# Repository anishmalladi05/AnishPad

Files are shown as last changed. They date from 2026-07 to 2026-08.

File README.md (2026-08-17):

# AnishPad
I made this Macropad because I wanted one that was more customizable then my last, which only had 4 buttons. That time, the rotary encoder got the better of me, so I wanted to successfully put one in this time, which I did!
<br></br>
A 5 key, 1 rotary encoder, and 128 x 32 oled display macropad.

# Images:

Screenshot 2026-08-17 at 3 21 54 PM
Screenshot 2026-08-17 at 3 21 58 PM
Screenshot 2026-08-17 at 3 22 01 PM
Screenshot 2026-08-17 at 3 22 04 PM

<br></br>
# To Flash:
Put the microcontroller in bootloader mode. (Hold reset, double press boot, release reset)
<br></br>
Plug into computer
<br></br>
Drag UF2 file into microcontroller
<br></br>

Replace boot_out.txt with boot_out.txt in my gihub repo under CIRCUITPY FILES
<br></br>
Replace code.py with code.py from my repo
<br></br>
Add boot.txt from my repo
<br></br>
Add boot.py from my repo
<br></br>

It should start working!

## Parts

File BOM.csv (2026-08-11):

Item | "Link" | "Price"
5x MX CHERRY SWITCES: | https://www.amazon.com/CHERRY-Switch-Mechanical-Keyboard-Switches/dp/B0FYR9X5QH?sp_csd=d2lkZ2V0TmFtZT1zcF9hdGY | "$15"
1x 128x32 OLED panel (needs to allow for 5v): | https://www.amazon.com/dp/B079BN2J8V?lv=shuf&channelId=500&plpRedirect=mhFallback&th=1 | "$8"
5x Keycaps (Can buy own, or 3d print files are in the CAD folder): | https://www.amazon.com/Elacgap-Profile-switches-Mechanical-Keyboard/dp/B0CQ2Y15Y5 | "$12"
1x SEEEDUINO XIAO RP2040: | https://www.seeedstudio.com/Seeed-Studio-XIAO-ESP32S3-Pre-Soldered-p-6334.html | "$4"
1x Ability to solder: | Please provide yourself | "Free!"
1x EC11 Push button rotary encoder (the one wihtout the PCB attached): | https://www.amazon.com/QSYZAIL-Rotary-Encoder-Compatible-Arduino/dp/B0G528SYTB?sp_csd=d2lkZ2V0TmFtZT1zcF9hdGY | "$8"
1x PCB (found in PCB files): | jlcpcb.com | "$4"
1x UCB-C cable to connect to device: | https://www.amazon.com/Amazon-Basics-Charger-480Mbps-Certified/dp/B01GGKZ2SC?sp_csd=d2lkZ2V0TmFtZT1zcF9hdGY | "$10"
1x Coding skills (only if you want to customize or make it work for windows): | Please provide yourself | "Free again!"
1x 3D printer with 1 spool filament: | https://us.store.bambulab.com/products/a1-mini?from=navigation | "$220"
3x Socket head cap screws SHCS.M316-50: | https://www.mcmaster.com/products/cap-screws/fastener-head-type~socket/?matchtype=p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 | "$5"

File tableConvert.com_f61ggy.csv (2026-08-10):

5x MX CHERRY SWITCES: | https://www.amazon.com/CHERRY-Switch-Mechanical-Keyboard-Switches/dp/B0FYR9X5QH?sp_csd=d2lkZ2V0TmFtZT1zcF9hdGY
1x 128x32 OLED panel (needs to allow for 5v): | https://www.amazon.com/dp/B079BN2J8V?lv=shuf&channelId=500&plpRedirect=mhFallback&th=1
5x Keycaps (Can buy own, or 3d print files are in the CAD folder): | https://www.amazon.com/Elacgap-Profile-switches-Mechanical-Keyboard/dp/B0CQ2Y15Y5
1x SEEEDUINO XIAO RP2040: | https://www.seeedstudio.com/Seeed-Studio-XIAO-ESP32S3-Pre-Soldered-p-6334.html
1x Ability to solder: | Please provide yourself
1x EC11 Push button rotary encoder (the one wihtout the PCB attached): | https://www.amazon.com/QSYZAIL-Rotary-Encoder-Compatible-Arduino/dp/B0G528SYTB?sp_csd=d2lkZ2V0TmFtZT1zcF9hdGY
1x PCB (found in PCB files): | jlcpcb.com
1x UCB-C cable to connect to device: | https://www.amazon.com/Amazon-Basics-Charger-480Mbps-Certified/dp/B01GGKZ2SC?sp_csd=d2lkZ2V0TmFtZT1zcF9hdGY
1x Coding skills (only if you want to customize or make it work for windows): | Please provide yourself
1x 3D printer with 1 spool filament: | https://us.store.bambulab.com/products/a1-mini?from=navigation
3x Socket head cap screws SHCS.M316-50: | https://www.mcmaster.com/products/cap-screws/fastener-head-type~socket/?matchtype=p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

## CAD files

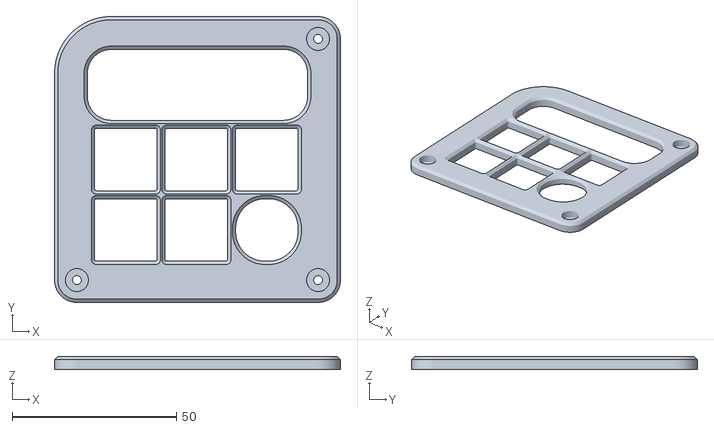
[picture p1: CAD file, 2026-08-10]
AnishPad CAD/TopCover.stl
87.0 x 87.0 x 4.04

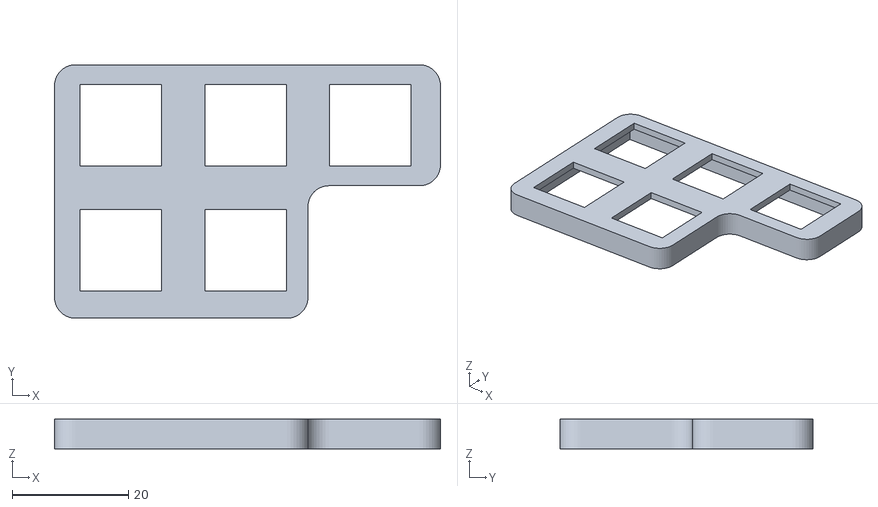
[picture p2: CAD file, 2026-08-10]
AnishPad CAD/KeyAligners.stl
66.3 x 43.5 x 5.13

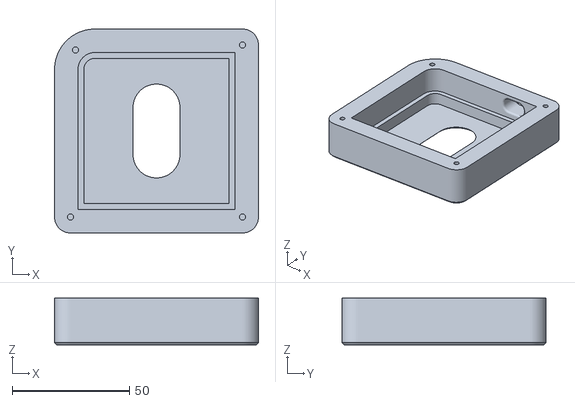
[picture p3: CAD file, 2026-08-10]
AnishPad CAD/BottomCover.stl
87.0 x 87.0 x 20.0

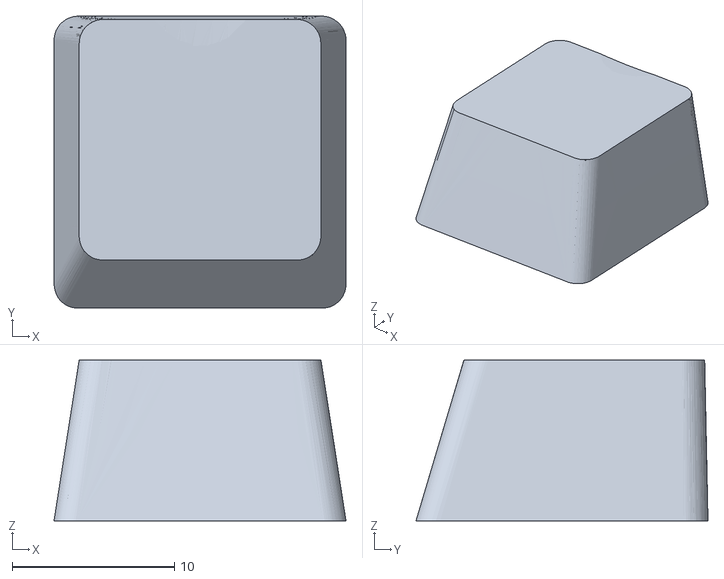
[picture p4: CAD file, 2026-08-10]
AnishPad CAD/KeyCap.stl
18.0 x 18.0 x 9.91

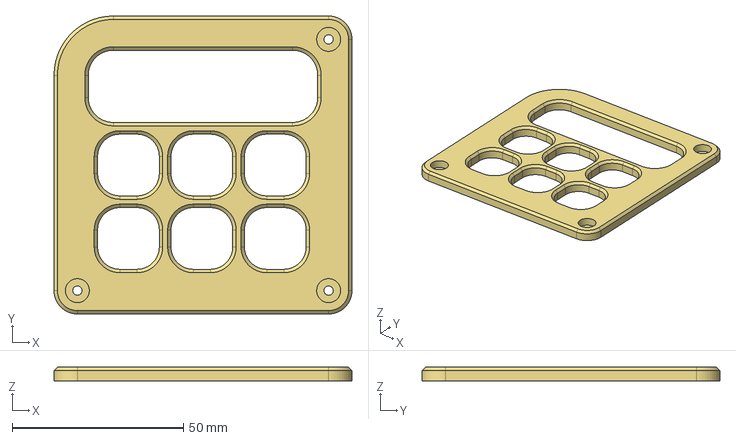
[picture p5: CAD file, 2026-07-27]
AnishPad CAD/AnishPad Case Top.step
87.0 x 87.0 x 4.04 mm

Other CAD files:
AnishPad CAD/AnishPad Keycap.step
AnishPad CAD/AnishPad Case Bottom.step

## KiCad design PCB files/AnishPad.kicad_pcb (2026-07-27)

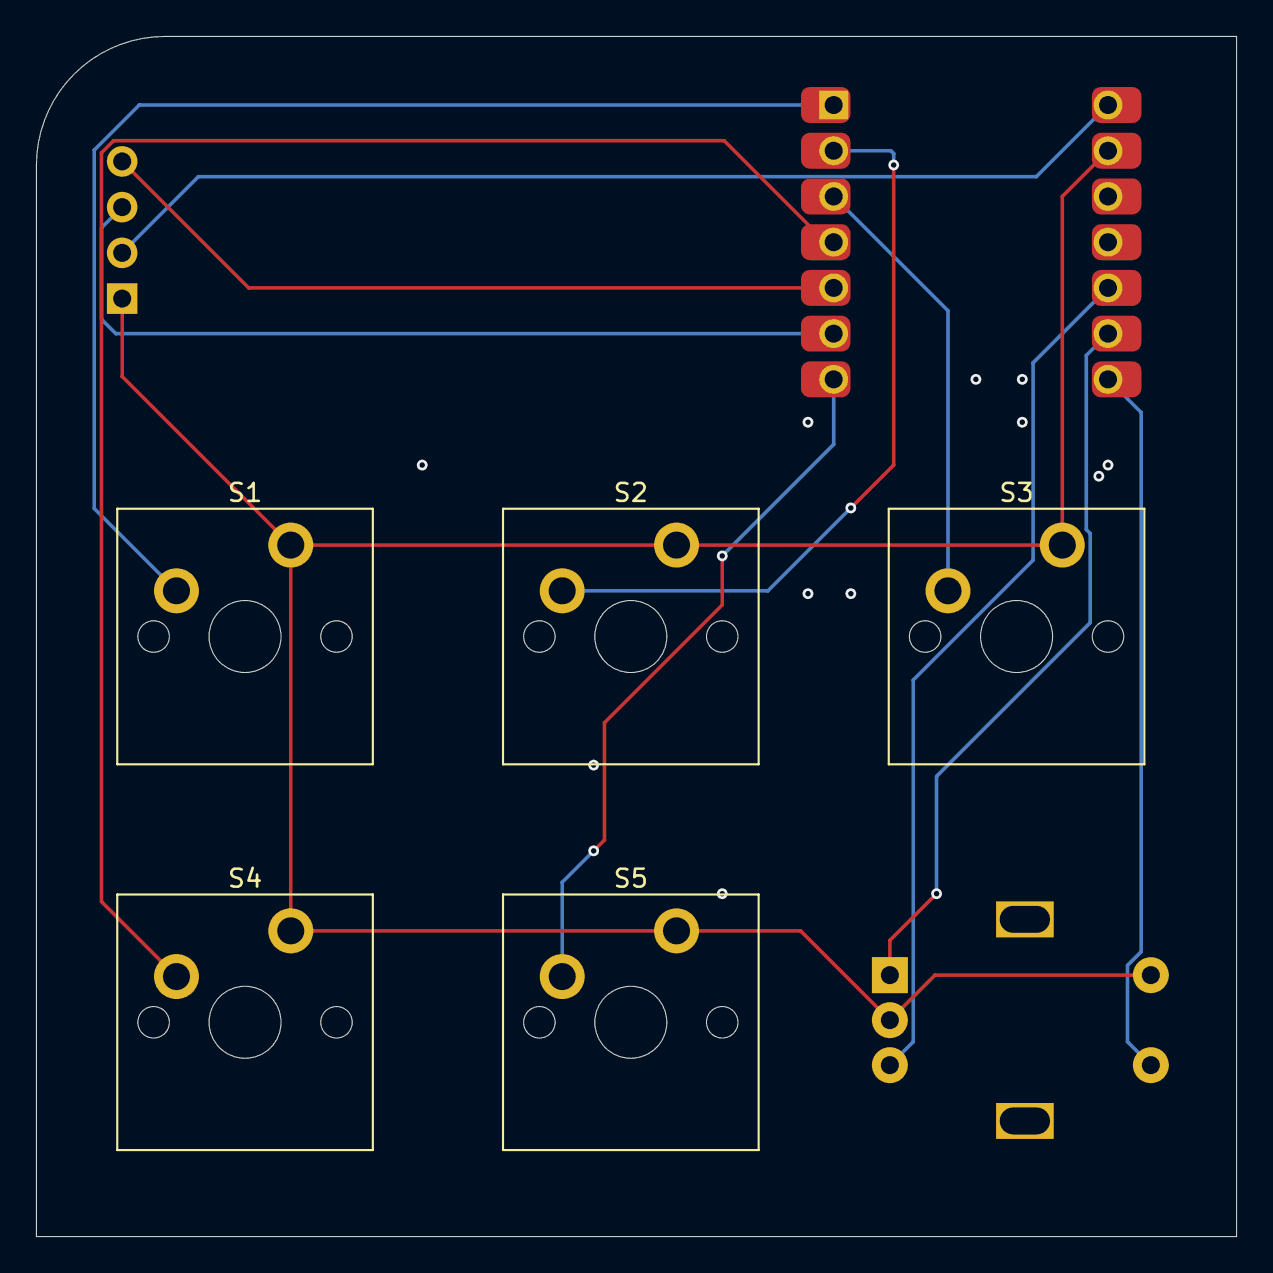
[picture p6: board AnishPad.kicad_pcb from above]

Board: 2 copper layers, 66.7 x 66.7 mm, 8 parts (0 on the bottom side), 12 nets.

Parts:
J1: OLED_128x32
S1, S2, S3, S4, S5: MX_PCB_1.00u
SW6: RotaryEncoder_Switch; Encoder_EC11_MX
U1: MOUDLE-SEEEDUINO-XIAO; Seeed_XIAO_RP2040

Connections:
1: S1.1, U1.1 (PA02_A0_D0)
2: S2.1, U1.2 (PA4_A1_D1)
3: S3.1, U1.3 (PA10_A2_D2)
4: S4.1, U1.4 (PA11_A3_D3)
5: J1.4 (SDA), U1.5 (PA8_A4_D4_SDA)
6: J1.3 (SCL), U1.6 (PA9_A5_D5_SCL)
7: S5.1, U1.7 (PB08_A6_D6_TX)
8: SW6.S1, U1.8 (PB09_A7_D7_RX)
9: SW6.A, U1.9 (PA7_A8_D8_SCK)
10: SW6.B, U1.10 (PA5_A9_D9_MISO)
13: J1.1 (GND), S1.2, S2.2, S3.2, S4.2, S5.2, SW6.C, SW6.S2, U1.13 (GND)
14: J1.2 (VCC), U1.14 (5V)

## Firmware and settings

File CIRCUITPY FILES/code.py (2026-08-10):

import math
import time
import board
import displayio
import terminalio
import digitalio
import usb_hid
from adafruit_display_text import label
import adafruit_displayio_ssd1306
from adafruit_hid.keyboard import Keyboard
from adafruit_hid.keycode import Keycode
from adafruit_hid.consumer_control import ConsumerControl
from adafruit_hid.consumer_control_code import ConsumerControlCode

try:
    from i2cdisplaybus import I2CDisplayBus
except ImportError:
    from displayio import I2CDisplay as I2CDisplayBus

displayio.release_displays()

i2c = board.I2C()
display_bus = I2CDisplayBus(i2c, device_address=0x3C)

WIDTH = 128
HEIGHT = 32

display = adafruit_displayio_ssd1306.SSD1306(display_bus, width=WIDTH, height=HEIGHT, rotation=0)

splash = displayio.Group()
display.root_group = splash

# --- UI LABELS SETUP ---
layer_label = label.Label(terminalio.FONT, text="N", color=0xFFFFFF)
layer_label.x = 100
layer_label.y = 8
splash.append(layer_label)

mode_label = label.Label(terminalio.FONT, text="VOL", color=0xFFFFFF)
mode_label.x = 100
mode_label.y = 24
splash.append(mode_label)

grid_labels = []
coords = [(10, 8), (52, 8), (10, 24), (52, 24)]
for coord in coords:
    lbl = label.Label(terminalio.FONT, text="-", color=0xFFFFFF)
    lbl.x = coord[0]
    lbl.y = coord[1]
    splash.append(lbl)
    grid_labels.append(lbl)

# --- HID & INPUT SETUP ---
kbd = Keyboard(usb_hid.devices)
cc = ConsumerControl(usb_hid.devices)

# Switches S1-S5 mapped to D0, D1, D2, D3, TX
switch_pins = [board.D0, board.D1, board.D2, board.D3, board.TX]
switches = []
for pin in switch_pins:
    sw = digitalio.DigitalInOut(pin)
    sw.direction = digitalio.Direction.INPUT
    sw.pull = digitalio.Pull.UP
    switches.append(sw)

last_switch_states = [True] * len(switches)

# Rotary Encoder Push Button (SW6) on RX
encoder_button = digitalio.DigitalInOut(board.RX)
encoder_button.direction = digitalio.Direction.INPUT
encoder_button.pull = digitalio.Pull.UP
last_button_state = True

# Software Rotary Encoder Pins on D8 and D9
enc_a = digitalio.DigitalInOut(board.D8)
enc_a.direction = digitalio.Direction.INPUT
enc_a.pull = digitalio.Pull.UP

enc_b = digitalio.DigitalInOut(board.D9)
enc_b.direction = digitalio.Direction.INPUT
enc_b.pull = digitalio.Pull.UP

last_a_state = enc_a.value

# --- LAYER & MODE STATE ---
current_layer = 0
layer_key_index = 2
last_layer_key_state = True

# Double-click tracking variables
click_count = 0
first_click_time = 0.0
double_click_window = 0.35  # Max seconds between taps for a double-click

control_mode = "VOLUME"

# Layer display names mapped to N, M, S, F
layer_names_list = ["N", "M", "S", "F"]

# 4 Layers of key mappings and display names:
# Order for keys/names: [S1, S2, S4, S5, Encoder Button]
layer_data = [
    {
        "keys": [
            [Keycode.LEFT_GUI, Keycode.Z],                       # S1: Cmd + Z
            [Keycode.LEFT_GUI, Keycode.LEFT_SHIFT, Keycode.Z],   # S2: Cmd + Shift + Z
            [Keycode.LEFT_GUI, Keycode.SPACE],                   # S3: Cmd + Space
            [Keycode.LEFT_GUI, Keycode.TAB],                     # S4: Cmd + Tab
            [Keycode.LEFT_GUI]                                   # Encoder Button
        ],
        "names": ["Undo", "Redo", "Spot", "Tab"]
    },
    {
        "keys": [
            [Keycode.LEFT_GUI, Keycode.Z],                       # S1: Cmd + Z
            [Keycode.LEFT_GUI, Keycode.LEFT_SHIFT, Keycode.Z],   # S2: Cmd + Shift + Z
            [Keycode.LEFT_GUI, Keycode.S],                       # S3: Cmd + S
            [Keycode.LEFT_GUI, Keycode.LEFT_CONTROL, Keycode.F], # S4: Cmd + Ctrl + F
            [Keycode.LEFT_GUI]                                   # Encoder Button
        ],
        "names": ["Undo", "Redo", "Save", "Full"]
    },
    {
        "keys": [
            [Keycode.LEFT_GUI, Keycode.W],                       # S1: Cmd + W
            [Keycode.LEFT_GUI, Keycode.N],                       # S2: Cmd + N
            [Keycode.LEFT_GUI, Keycode.ONE],                     # S3: Cmd + 1
            [Keycode.LEFT_GUI, Keycode.LEFT_SHIFT, Keycode.L],   # S4: Shift + Cmd + L
            [Keycode.LEFT_GUI]                                   # Encoder Button
        ],
        "names": ["Close", "New", "First", "Side"]
    },
    {
        "keys": [
            [Keycode.L],                                         # S1: L
            [Keycode.D],                                         # S2: D
            [Keycode.LEFT_GUI, Keycode.S],                       # S3: Cmd + S
            [Keycode.ENTER],                                     # S4: Enter
            [Keycode.LEFT_GUI]                                   # Encoder Button
        ],
        "names": ["Line", "Dime", "Save", "Enter"]
    },
]

def update_display_text():
    layer_label.text = layer_names_list[current_layer]
    mode_label.text = "VOL" if control_mode == "VOLUME" else "BRI"
    
    active_names = layer_data[current_layer]["names"]
    grid_labels[0].text = active_names[0]
    grid_labels[1].text = active_names[1]
    grid_labels[2].text = active_names[2]
    grid_labels[3].text = active_names[3]

update_display_text()

while True:
    # 2. Check Layer Switch (D2 / index 2) with Double-Click logic
    current_layer_key_state = switches[layer_key_index].value
    if last_layer_key_state and not current_layer_key_state:
        # Button was just pressed down
        now = time.monotonic()
        if click_count == 0:
            click_count = 1
            first_click_time = now
        elif click_count == 1:
            if (now - first_click_time) <= double_click_window:
                # Double click detected: Go backward 1 layer
                current_layer = (current_layer - 1) % 4
                print(f"Double Click! Switched backward to Layer: {layer_names_list[current_layer]}")
                update_display_text()
                click_count = 0
            else:
                # Too slow, treat this press as the start of a new single click
                click_count = 1
                first_click_time = now
    last_layer_key_state = current_layer_key_state

    # Check if the single-click window has expired to execute forward step
    if click_count == 1 and (time.monotonic() - first_click_time) > double_click_window:
        current_layer = (current_layer + 1) % 4
        print(f"Single Click! Switched forward to Layer: {layer_names_list[current_layer]}")
        update_display_text()
        click_count = 0

    # 3. Check S1, S2, S4, S5 Switches using current layer mapping
    active_layer_info = layer_data[current_layer]
    active_keys = active_layer_info["keys"]
    
    for i, sw in enumerate(switches):
        if i == layer_key_index:
            continue
            
        current_state = sw.value
        map_idx = i if i < 2 else i - 1
        
        if last_switch_states[i] and not current_state:
            for k in active_keys[map_idx]:
                kbd.press(k)
        elif not last_switch_states[i] and current_state:
            for k in active_keys[map_idx]:
                kbd.release(k)
        last_switch_states[i] = current_state

    # 4. Check Rotary Encoder Button Press (Toggles Mode & Types Layer Key)
    current_button_state = encoder_button.value
    if last_button_state and not current_button_state:
        if control_mode == "VOLUME":
            control_mode = "BRIGHTNESS"
            print("Control Mode: COMPUTER BRIGHTNESS")
        else:
            control_mode = "VOLUME"
            print("Control Mode: VOLUME")
            
        update_display_text()
        for k in active_keys[4]:
            kbd.press(k)
    elif not last_button_state and current_button_state:
        for k in active_keys[4]:
            kbd.release(k)
    last_button_state = current_button_state

    # 5. Check Software Rotary Encoder Rotation (Volume or Computer Brightness)
    current_a_state = enc_a.value
    if last_a_state and not current_a_state:
        direction = 1 if enc_b.value else -1
        
        if control_mode == "VOLUME":
            if direction > 0:
                cc.send(ConsumerControlCode.VOLUME_INCREMENT)
            else:
                cc.send(ConsumerControlCode.VOLUME_DECREMENT)
        elif control_mode == "BRIGHTNESS":
            if direction > 0:
                cc.send(ConsumerControlCode.BRIGHTNESS_INCREMENT)
            else:
                cc.send(ConsumerControlCode.BRIGHTNESS_DECREMENT)
            
    last_a_state = current_a_state

    time.sleep(0.005)

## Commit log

2026-08-10 Rename AnishPadFinal.step to AnishPad Cad/AnishPadFinal.step
    [AnishPadFinal.step]
2026-08-10 Rename boot.py to CIRCUITPY FILES/boot.py
2026-08-10 Rename boot.txt to CIRCUITPY FILES/boot.txt
2026-08-10 Rename code.py to CIRCUITPY FILES/code.py
2026-08-10 Add links for 3D printer and screws in README
2026-08-10 Add BOM.csv file
    [BOM.csv]
2026-08-11 Add prices and format corrections to BOM.csv
    Updated BOM.csv to include prices for items and corrected formatting.
    [BOM.csv]
